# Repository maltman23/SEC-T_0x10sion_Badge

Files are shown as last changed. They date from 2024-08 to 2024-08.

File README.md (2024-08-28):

# SEC-T 0x10sion Music Synthesizer Badge kit
photo of SEC-T 0x10sion Music Synthesizer Badge

The SEC-T 0x10sion Music Synthesizer Badge is a kit that attendees of SEC-T 0x10sion 2024 must solder together.
It is an Arduino-compatible music synthesizer kit with:
* a touch keyboard
* built-in speaker/amp
* audio output jack (for high-quality audio)
* 5 programmable RGB LEDs

It is designed to be perfect for total beginners to learn to solder and complete successfully.

The SEC-T Synth Badge comes with a pre-programmed music synthesizer that makes way cool sounds and music and noise.
Once soldering is completed, the SEC-T Synth Badge is a really nice, portable, performing musical instrument!

The SEC-T Synth Badge kit is based on the ArduTouch music synthesizer kit by Mitch Altman / Cornfield Electronics,
which is fully Open Hardware, with a CC BY-SA 4.0 license.

The SEC-T Synth Badge makes use of a modified ArduTouch library, which is available for
programming in more super nice synthesizer features, and for making your own synthesizers.
The library comes with examples (with more to come) that serve as a nice tutorial
on how to create your own SEC-T Synth Badge synthesizers (which are Arduino sketches).

The SEC-T Synth Badge is really just an Arduino Uno clone
with the features listed above, a couple of extra buttons, and a four of pots (for playing music and controlling the sounds).
The ArduTouch Arduino Library is where the real magic comes from!

For those who want to learn more, the documentation teaches the basics of Digital Signal Processing for audio generation.

The SEC-T Synth Badge kit is fully Open Hardware, with a CC BY-SA 4.0 license.
Open Hardware logo

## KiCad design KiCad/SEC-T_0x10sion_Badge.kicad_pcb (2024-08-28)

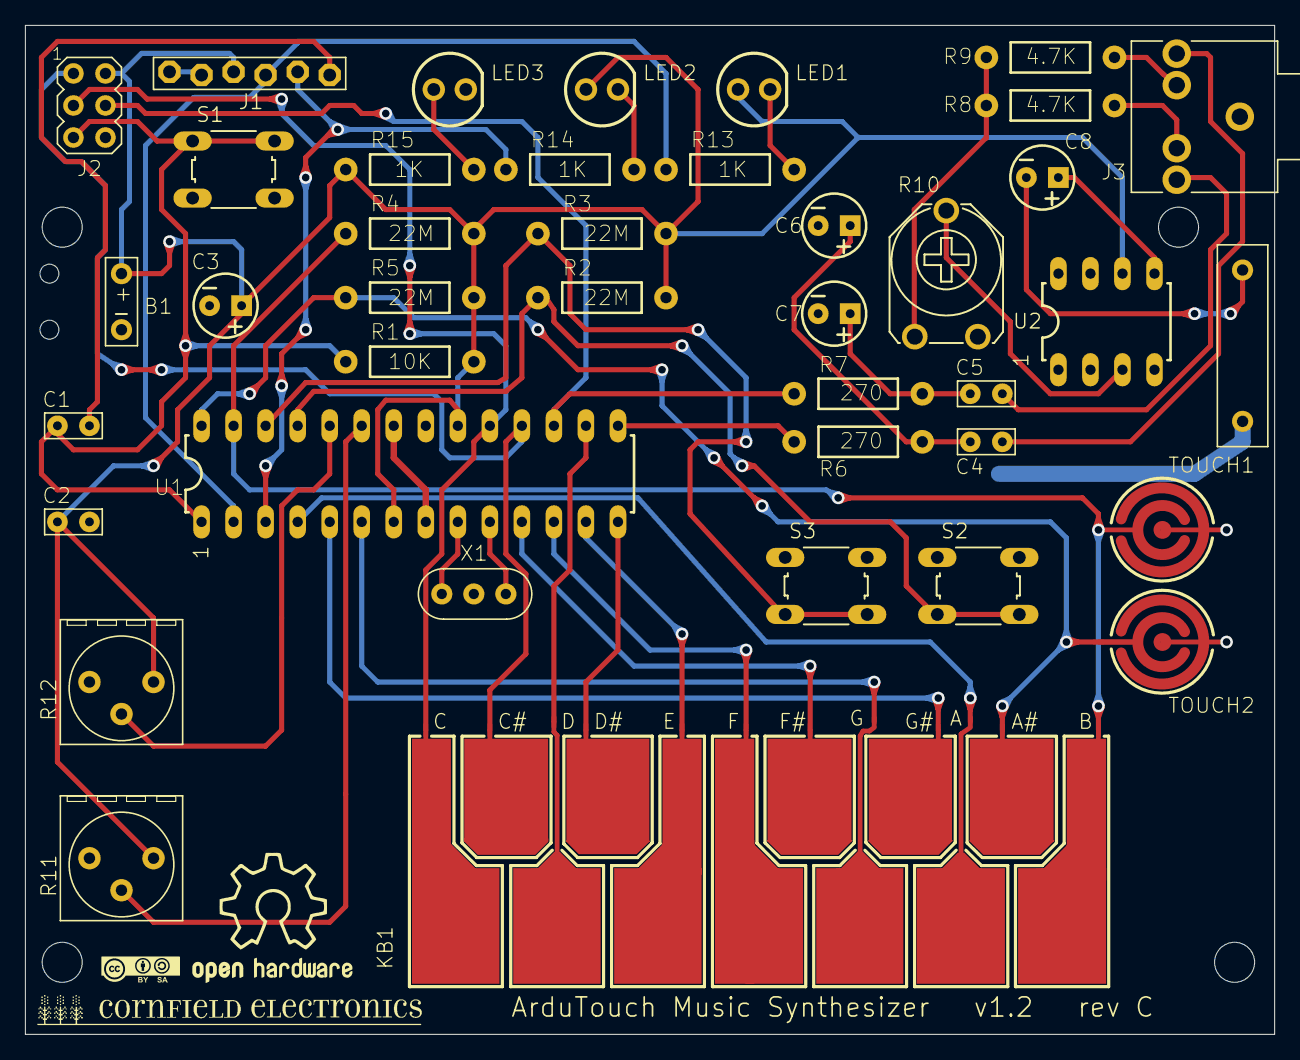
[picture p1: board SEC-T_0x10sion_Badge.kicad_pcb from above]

Board: 2 copper layers, 99.1 x 80.0 mm, 47 parts (0 on the bottom side), 39 nets.

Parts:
@HOLE0, @HOLE1, @HOLE2, @HOLE3: (no value)
B1: BATTERY-TERMINALS
C1, C2, C4, C5: 0.1uF; CAP-PTH-SMALL
C3, C8: 100uF; CPOL-RADIAL-10UF-25V
C6, C7: 1uF; CPOL-RADIAL-10UF-25V
J1: 1X06-BIGLOCK
J2: ISP; AVRISP
J3: STEREO-AUDIO-3.5MM-SWITCHED
KB1: PCB-KEYBOARD4
LED1: Blue; LED5MM
LED2: Red; LED5MM
LED3: Green; LED5MM
R1: 10K; AXIAL-0.4
R2, R3, R4, R5: 22M; AXIAL-0.4
R6, R7: 270; AXIAL-0.4
R8, R9: 4.7K; AXIAL-0.4
R10: 10K; TRIMPOT-3319P-1
R11, R12: 10K; TRIMPOT-72PTR
R13, R14, R15: 1K; AXIAL-0.4
S1, S2, S3: TACTILE_SWITCH_6.3MM
SPKR1: SPEAKER-TERMINALS
TOUCH1, TOUCH2: PCB-TOUCHPAD2
U1: ATmega328P; DIL28-3
U2: LM386; DIP08
U$1: OSH-LOGO
U$2: CC-BY-SA-LOGO2
U$3: CORNFIELD-LOGO
X1: 16.00MHz; CERM_OSC

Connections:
A: KB1.A, U1.4
A0: R11.2, U1.23
A1: R12.2, U1.24
A2: R2.P$1, S2.3, S2.4, U1.25
A#: KB1.A#, R5.P$1, TOUCH2.1, U1.28
AUDIO-LEFT: R6.P$1, U1.15
B: KB1.B, R4.P$1, TOUCH1.1, U1.27
C+: R3.P$1, S3.3, S3.4, U1.26
D: KB1.D, U1.16
D#: KB1.D#, U1.14
E: KB1.E, U1.13
F: KB1.F, U1.12
F#: KB1.F#, U1.11
G: KB1.G, U1.6
G#: KB1.G#, U1.5
GND: B1.-, C2.2, C3.-, C6.-, C7.-, J1.1, J1.2, J2.6, J3.1, LED3.K, R10.A, R11.3, R12.3, S1.3, S1.4, S2.1, S2.2, S3.1, S3.2, SPKR1.-, TOUCH1.2, TOUCH2.2, U1.8, U1.22, U2.2, U2.4, X1.P$2
MISO: J2.1, KB1.C#, U1.18
MOSI/AUDIO-RIGHT: J2.4, R7.P$1, U1.17
unnamed: C8.-, SPKR1.+
unnamed: U1.9, X1.P$1
unnamed: U1.10, X1.P$3
unnamed: C5.1, C7.+, R7.P$2
unnamed: C8.+, U2.5
unnamed: J3.3, R8.P$2
unnamed: J3.4, R9.P$2
unnamed: R10.S, U2.3
unnamed: C5.2, J3.2
unnamed: C4.1, C6.+, R6.P$2
unnamed: LED1.K, R13.P$2
unnamed: LED2.K, R14.P$2
unnamed: C4.2, J3.5
unnamed: LED3.A, R15.P$2
unnamed: R8.P$1, R9.P$1, R10.E
RESET*: C1.1, J2.5, R1.P$1, S1.1, S1.2, U1.1
RTS*: C1.2, J1.6
RXD: J1.4, R13.P$1, U1.2
SCK: J2.3, KB1.C, U1.19
TXD: J1.5, R14.P$1, U1.3
VCC: B1.+, C2.1, C3.+, J1.3, J2.2, LED1.A, LED2.A, R1.P$2, R2.P$2, R3.P$2, R4.P$2, R5.P$2, R11.1, R12.1, R15.P$1, U1.7, U1.20, U2.6

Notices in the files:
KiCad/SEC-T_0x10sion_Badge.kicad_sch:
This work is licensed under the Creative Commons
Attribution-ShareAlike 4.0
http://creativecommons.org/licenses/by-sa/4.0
